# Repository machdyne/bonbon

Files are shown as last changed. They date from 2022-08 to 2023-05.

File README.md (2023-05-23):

# Bonbon Computer

Bonbon is a compact FPGA computer designed by Lone Dynamics Corporation.

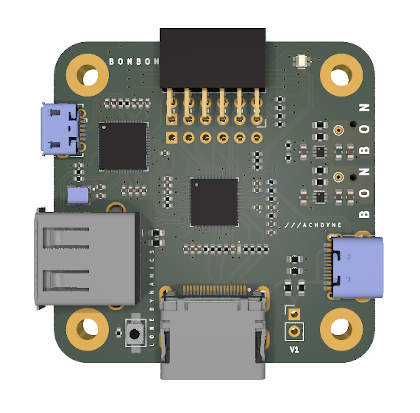
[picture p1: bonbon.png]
Bonbon Computer


This repo contains schematics, PCB layouts, pinouts, example firmware, gateware and documentation.

Find more information on the [Bonbon product page](https://machdyne.com/product/bonbon-computer/).

## Blinky 

Building the blinky example requires [Yosys](https://github.com/YosysHQ/yosys), [nextpnr-ice40](https://github.com/YosysHQ/nextpnr) and [IceStorm](https://github.com/YosysHQ/icestorm).

Assuming they are installed, you can simply type `make` to build the gateware, which will be written to output/blinky.bin. You can then connect the Micro-USB port to your computer and use the latest version of [ldprog](https://github.com/machdyne/ldprog) to write the gateware to the device.

## Programming

The RP2040 firmware, FPGA SRAM and flash MMOD can be programmed over the Micro-USB port.

Configure the FPGA SRAM:

```
$ ldprog -b -s blinky.bin
```

Program the flash MMOD:

```
$ ldprog -b -f blinky.bin
```

Note: It should also be possible to program the MMOD over the USB-C port with a USB bootloader but this is not yet officially supported.

## Firmware

Bonbon ships with RP2040 [firmware](firmware) based on the [Müsli](https://github.com/machdyne/musli) firmware which allows it to communicate with [ldprog](https://github.com/machdyne/ldprog).

The firmware is responsible for initializing the system, [configuring and outputting the system clock](https://raspberrypi.github.io/pico-sdk-doxygen/group__hardware__clocks.html#details), and either configuring the FPGA or telling the FPGA to configure itself from the MMOD.

The system clock (CLK\_RP) is 48MHz by default.

The firmware can be updated by holding down the BOOTSEL button, connecting the Micro-USB port to your computer, and then dragging and dropping a new UF2 file to the device filesystem.

## DDMI

See this [SmolDVI fork](https://github.com/machdyne/SmolDVI) for an example of outputting video on the DDMI port.

## Pinouts

 * [MMOD](https://github.com/machdyne/mmod)
 * [DDMI](https://github.com/machdyne/ddmi)

## License

The contents of this repo are released under the [Lone Dynamics Open License](LICENSE.md) with the following exceptions:

- The KiCad design files contain parts of the [kicad-pmod](https://github.com/mithro/kicad-pmod) library which is released under the [Apache License, Version 2.0](https://www.apache.org/licenses/LICENSE-2.0.html).

- The KiCad design files may contain symbols and footprints released under other licenses; please contact us if we've failed to give proper attribution.

Note: You can use these designs for commercial purposes but we ask that instead of producing exact clones, that you either replace our trademarks and logos with your own or add your own next to ours.

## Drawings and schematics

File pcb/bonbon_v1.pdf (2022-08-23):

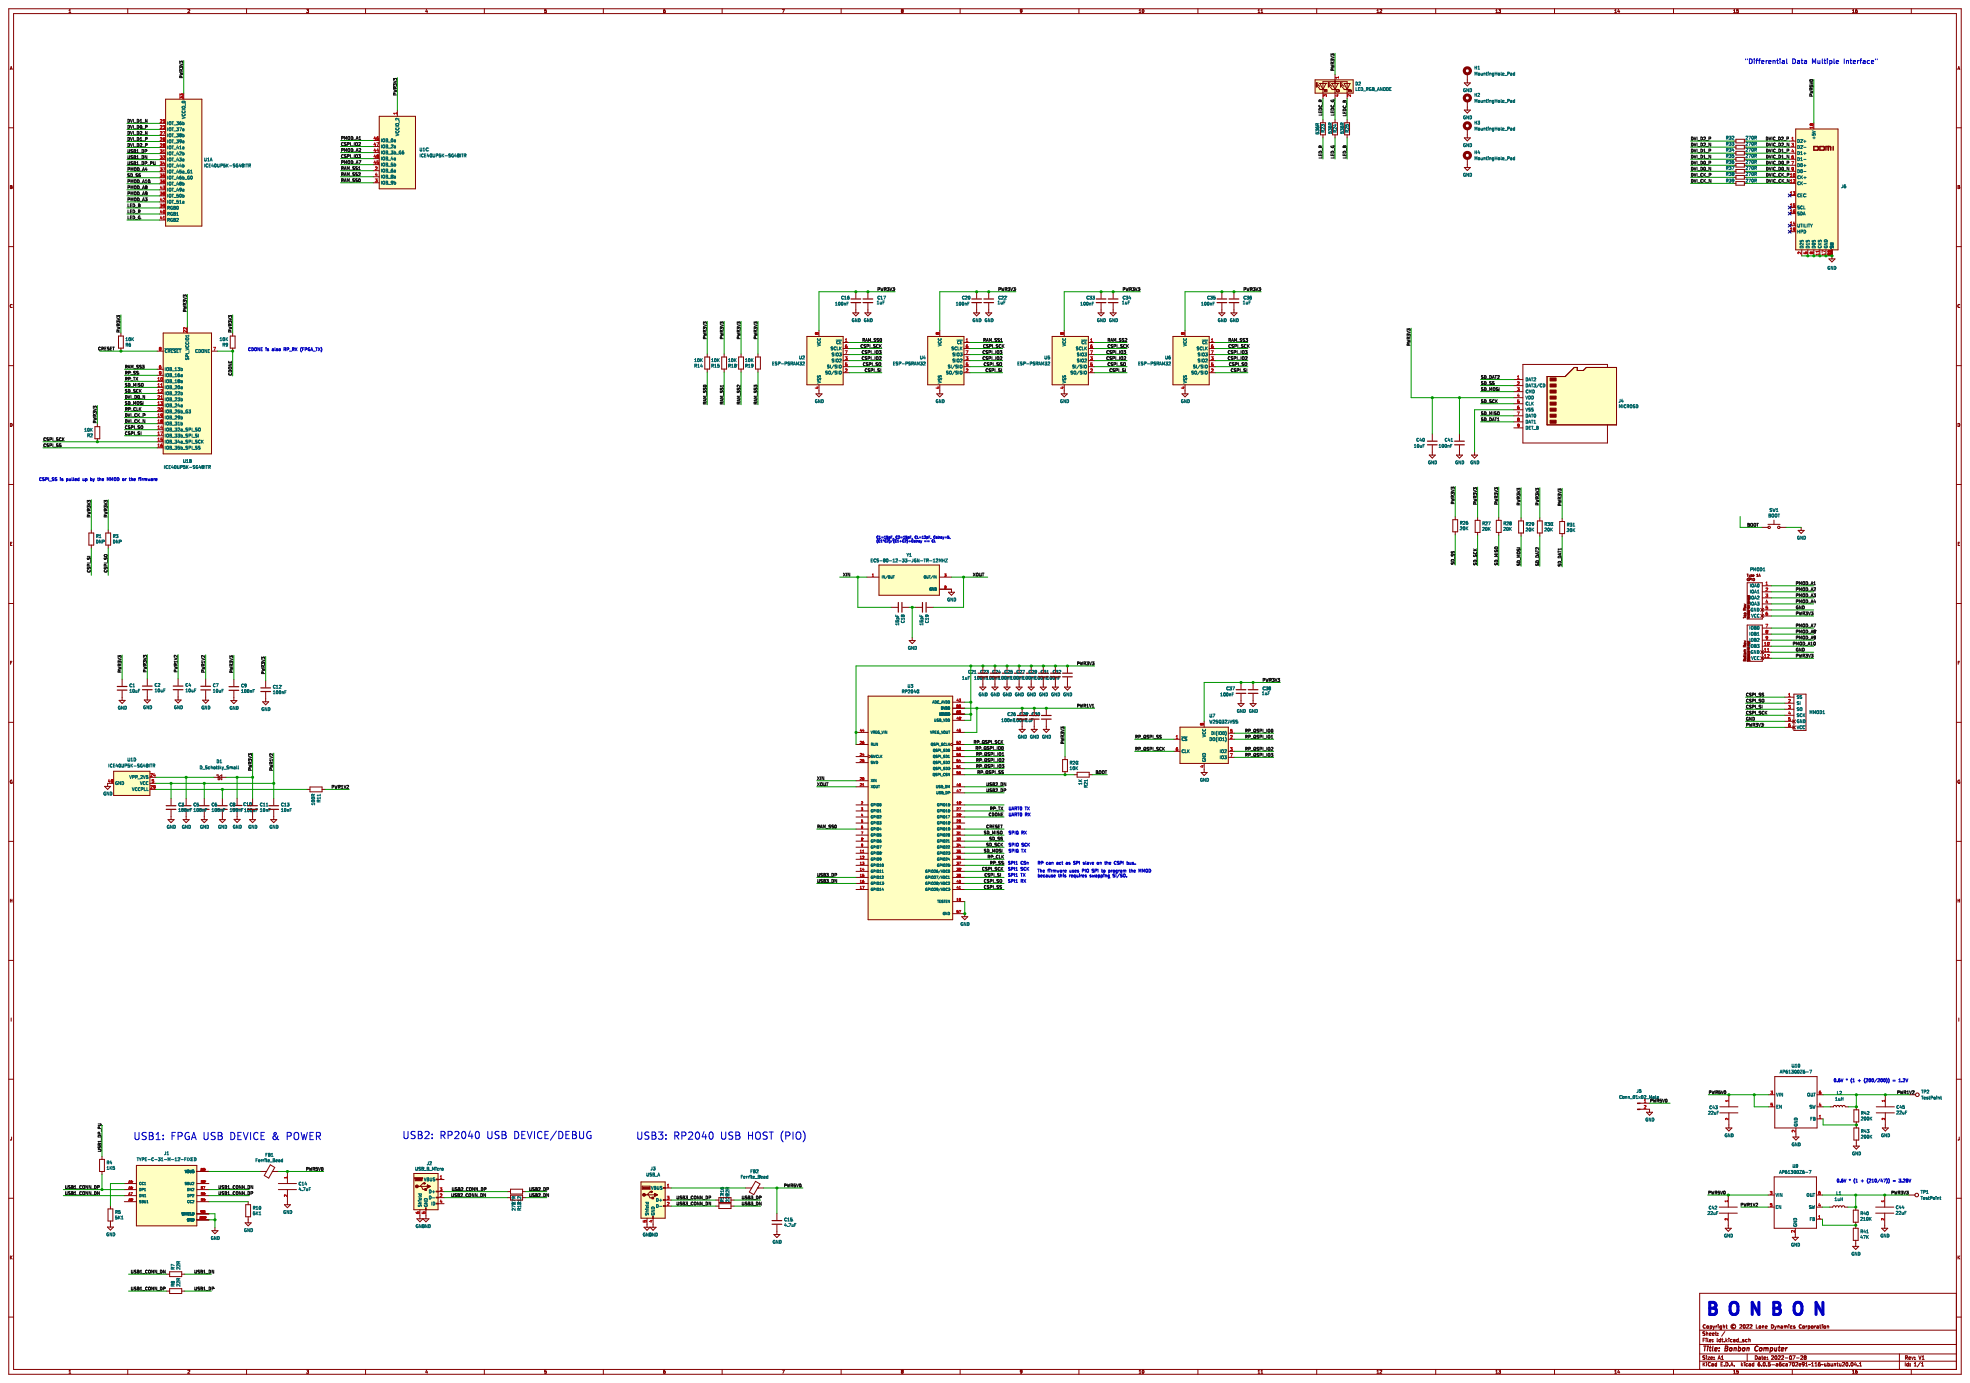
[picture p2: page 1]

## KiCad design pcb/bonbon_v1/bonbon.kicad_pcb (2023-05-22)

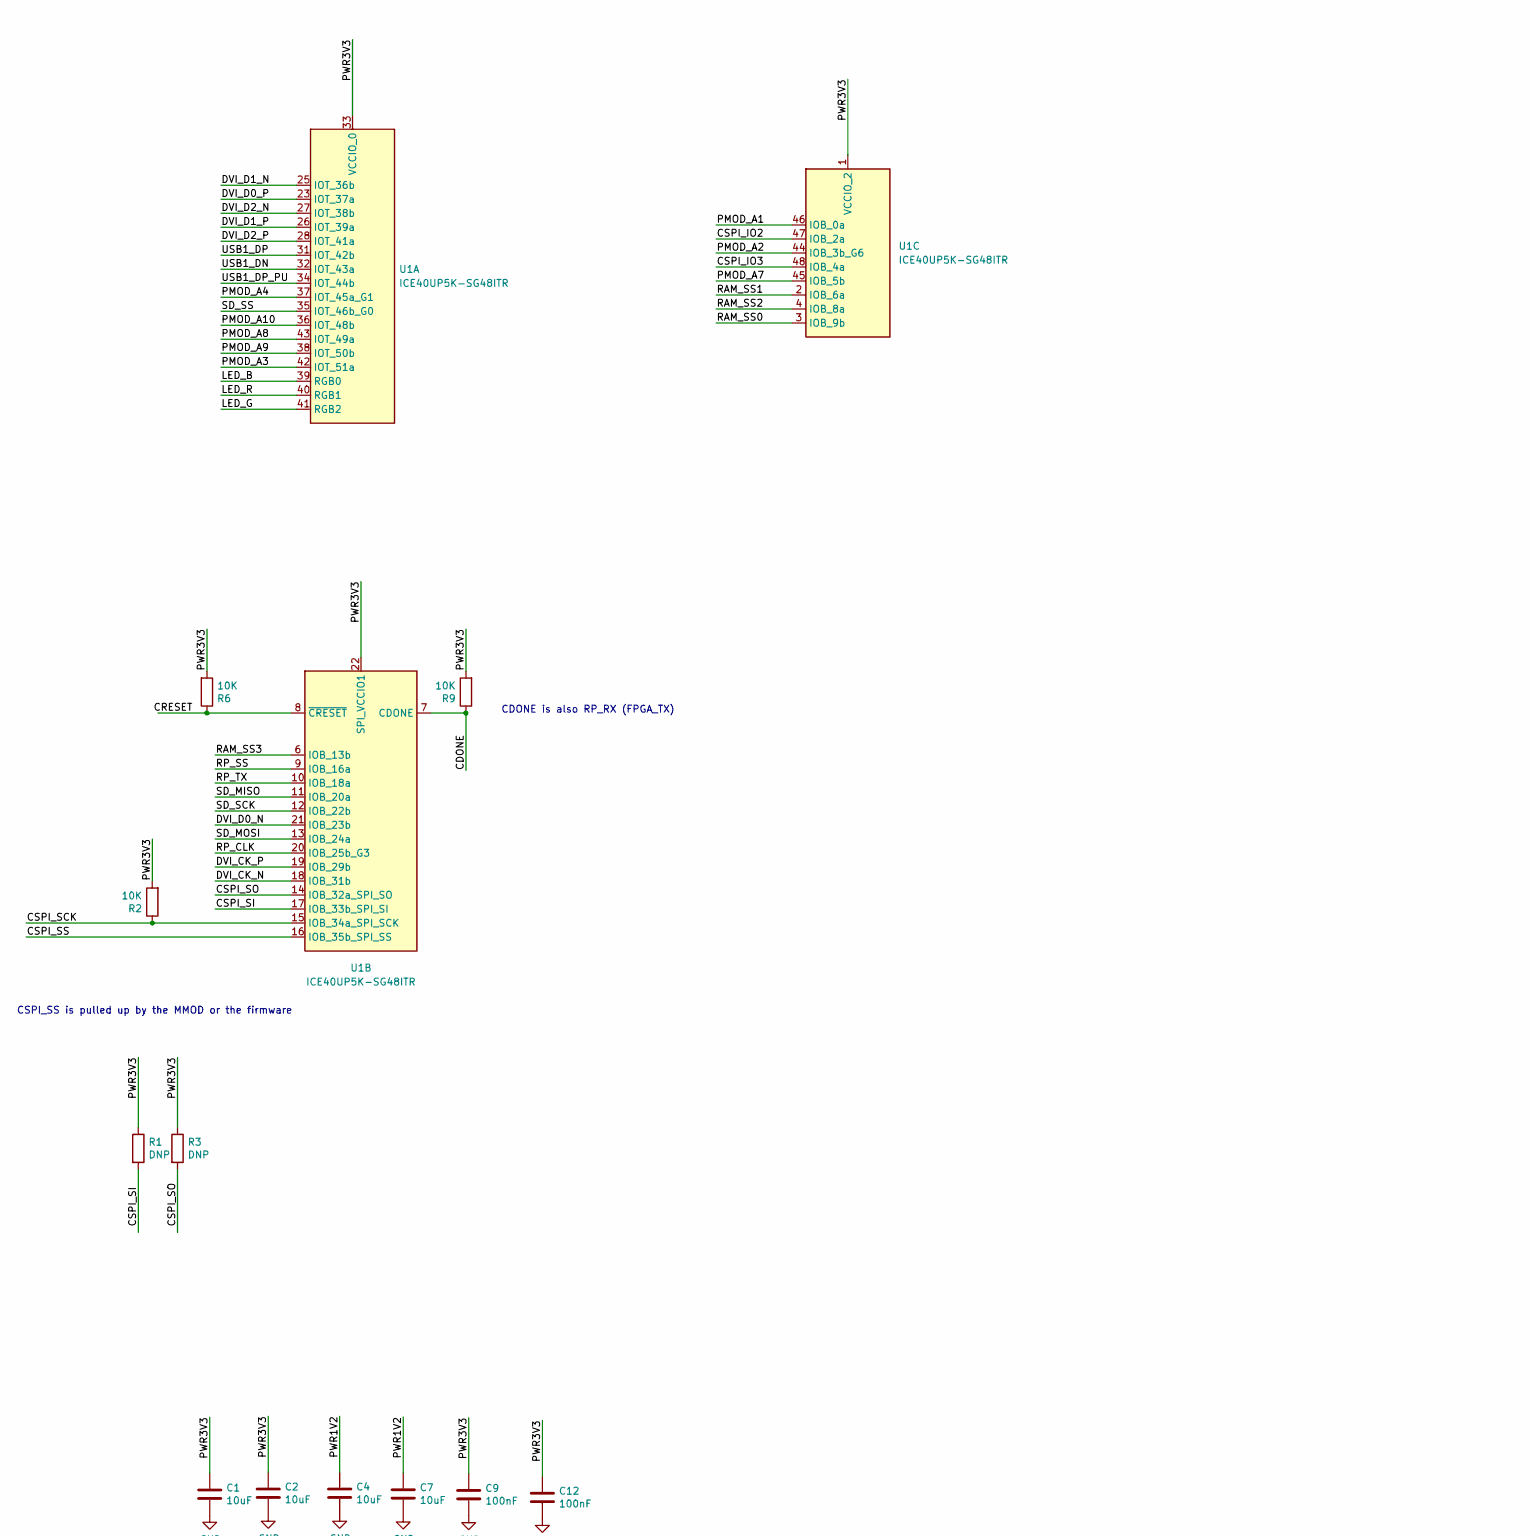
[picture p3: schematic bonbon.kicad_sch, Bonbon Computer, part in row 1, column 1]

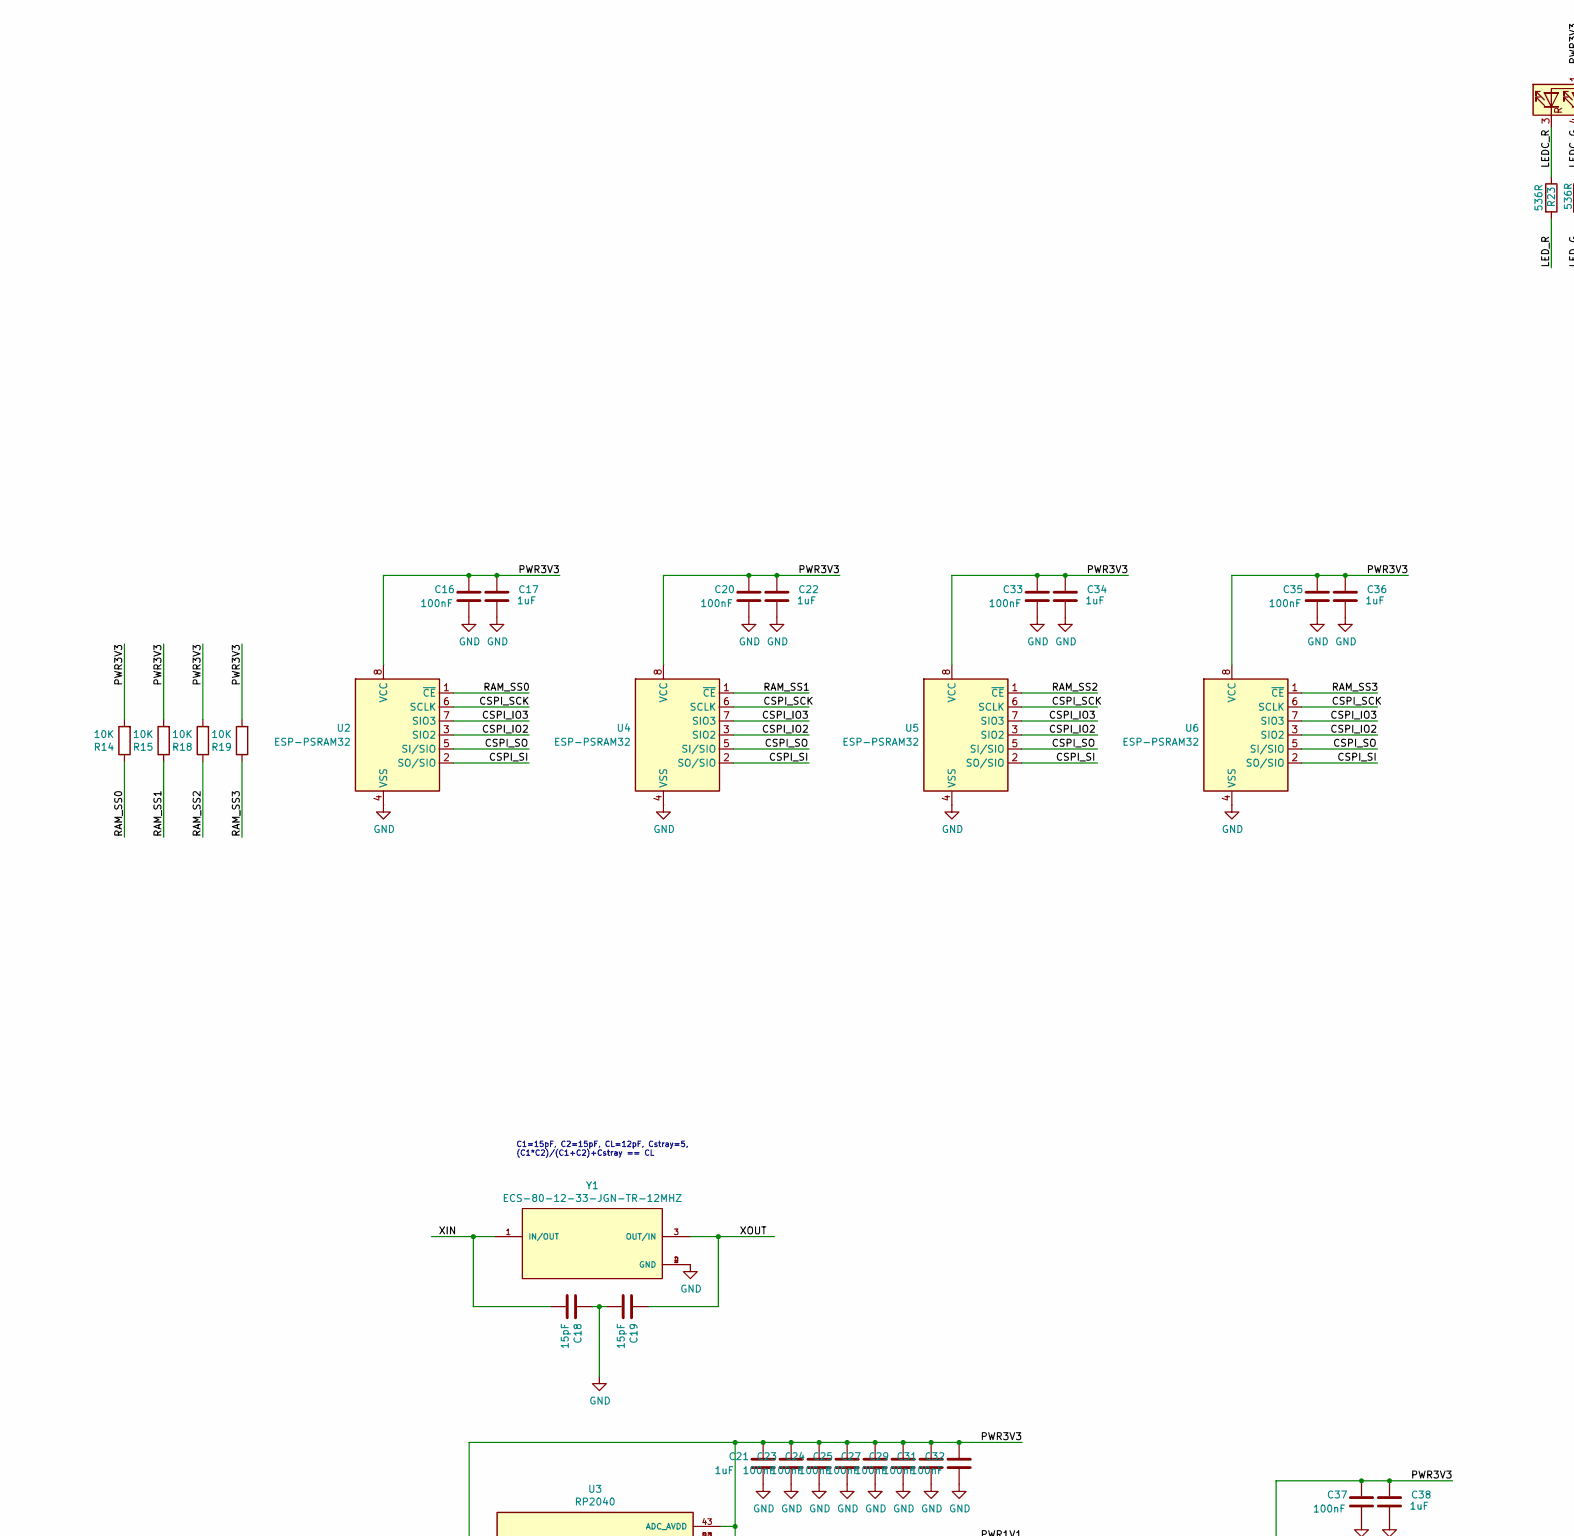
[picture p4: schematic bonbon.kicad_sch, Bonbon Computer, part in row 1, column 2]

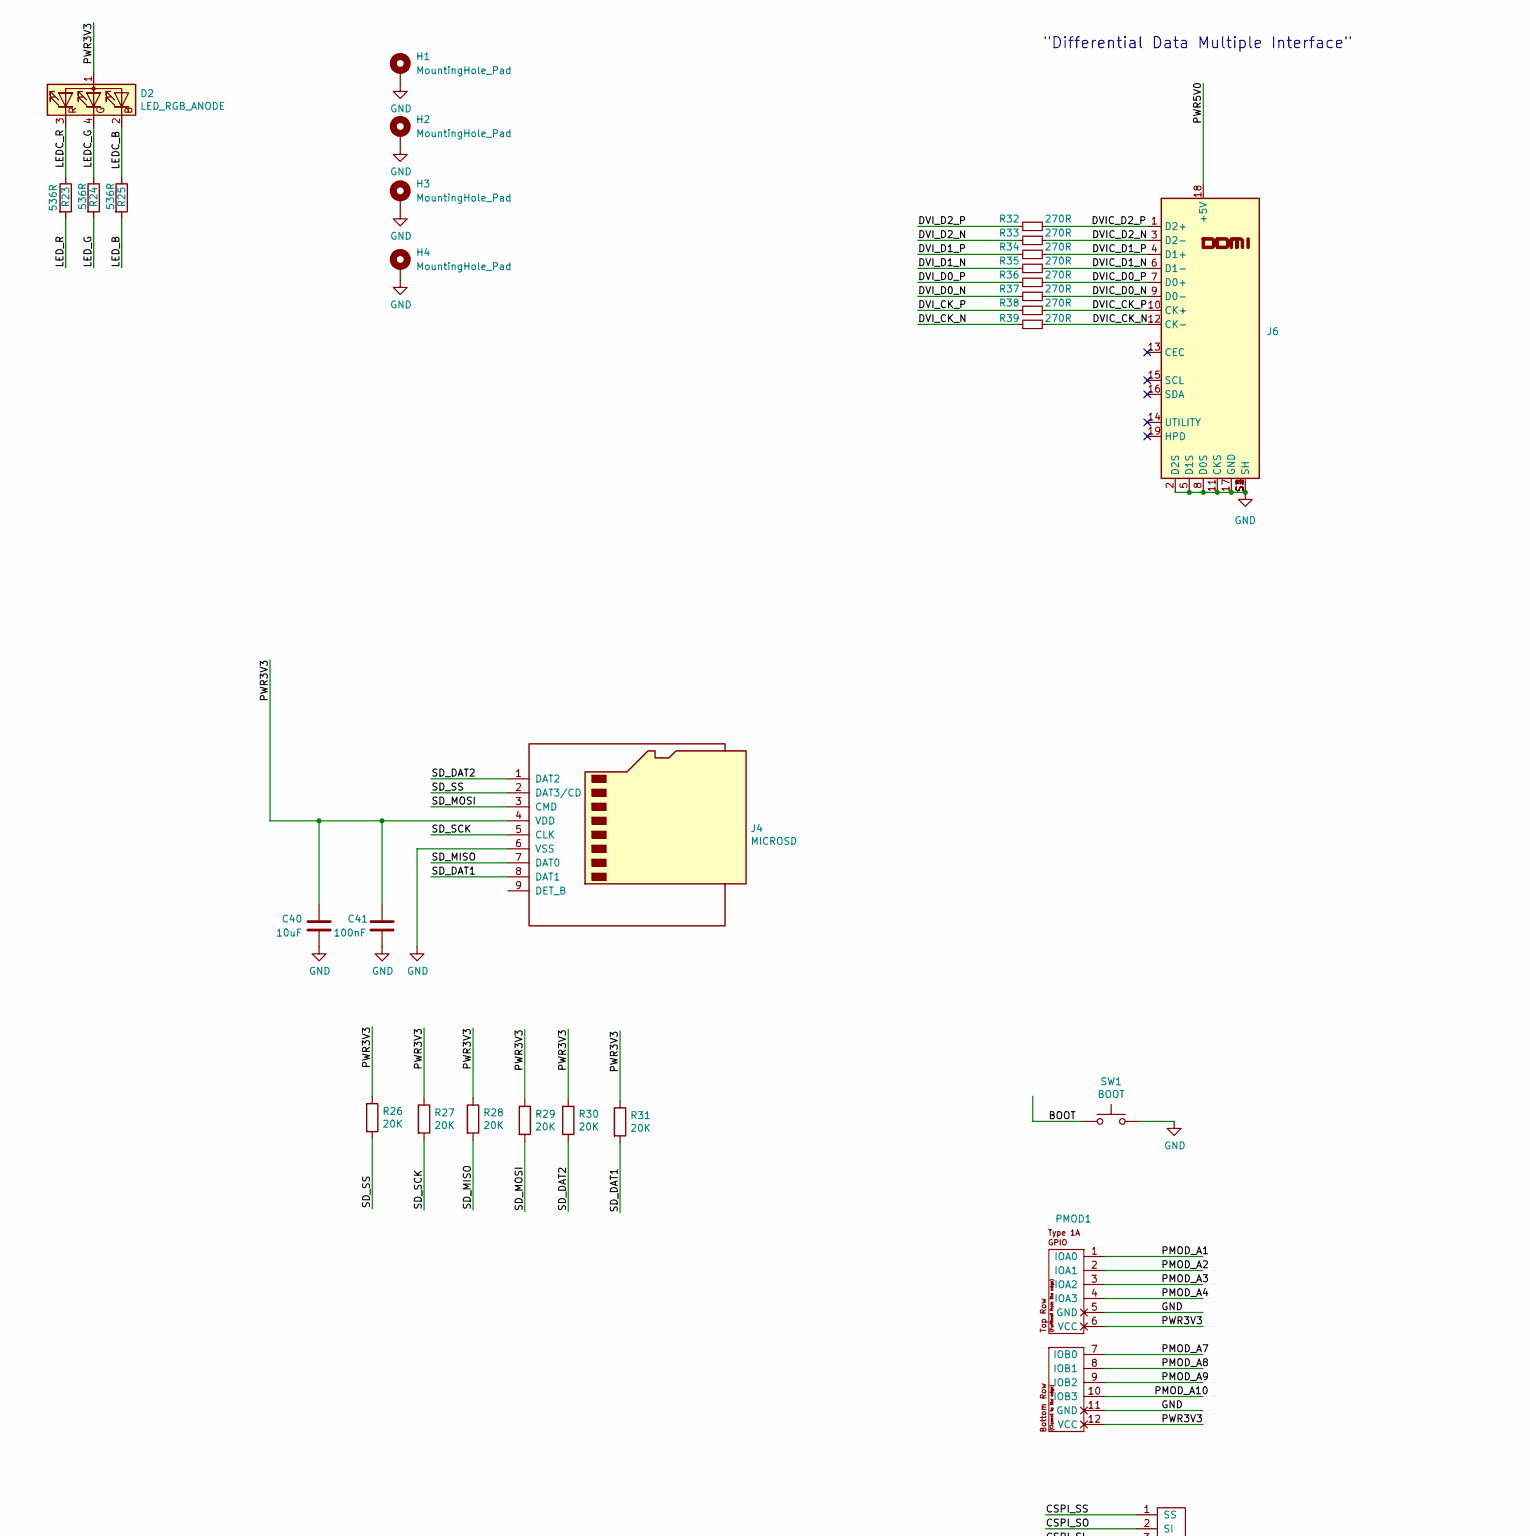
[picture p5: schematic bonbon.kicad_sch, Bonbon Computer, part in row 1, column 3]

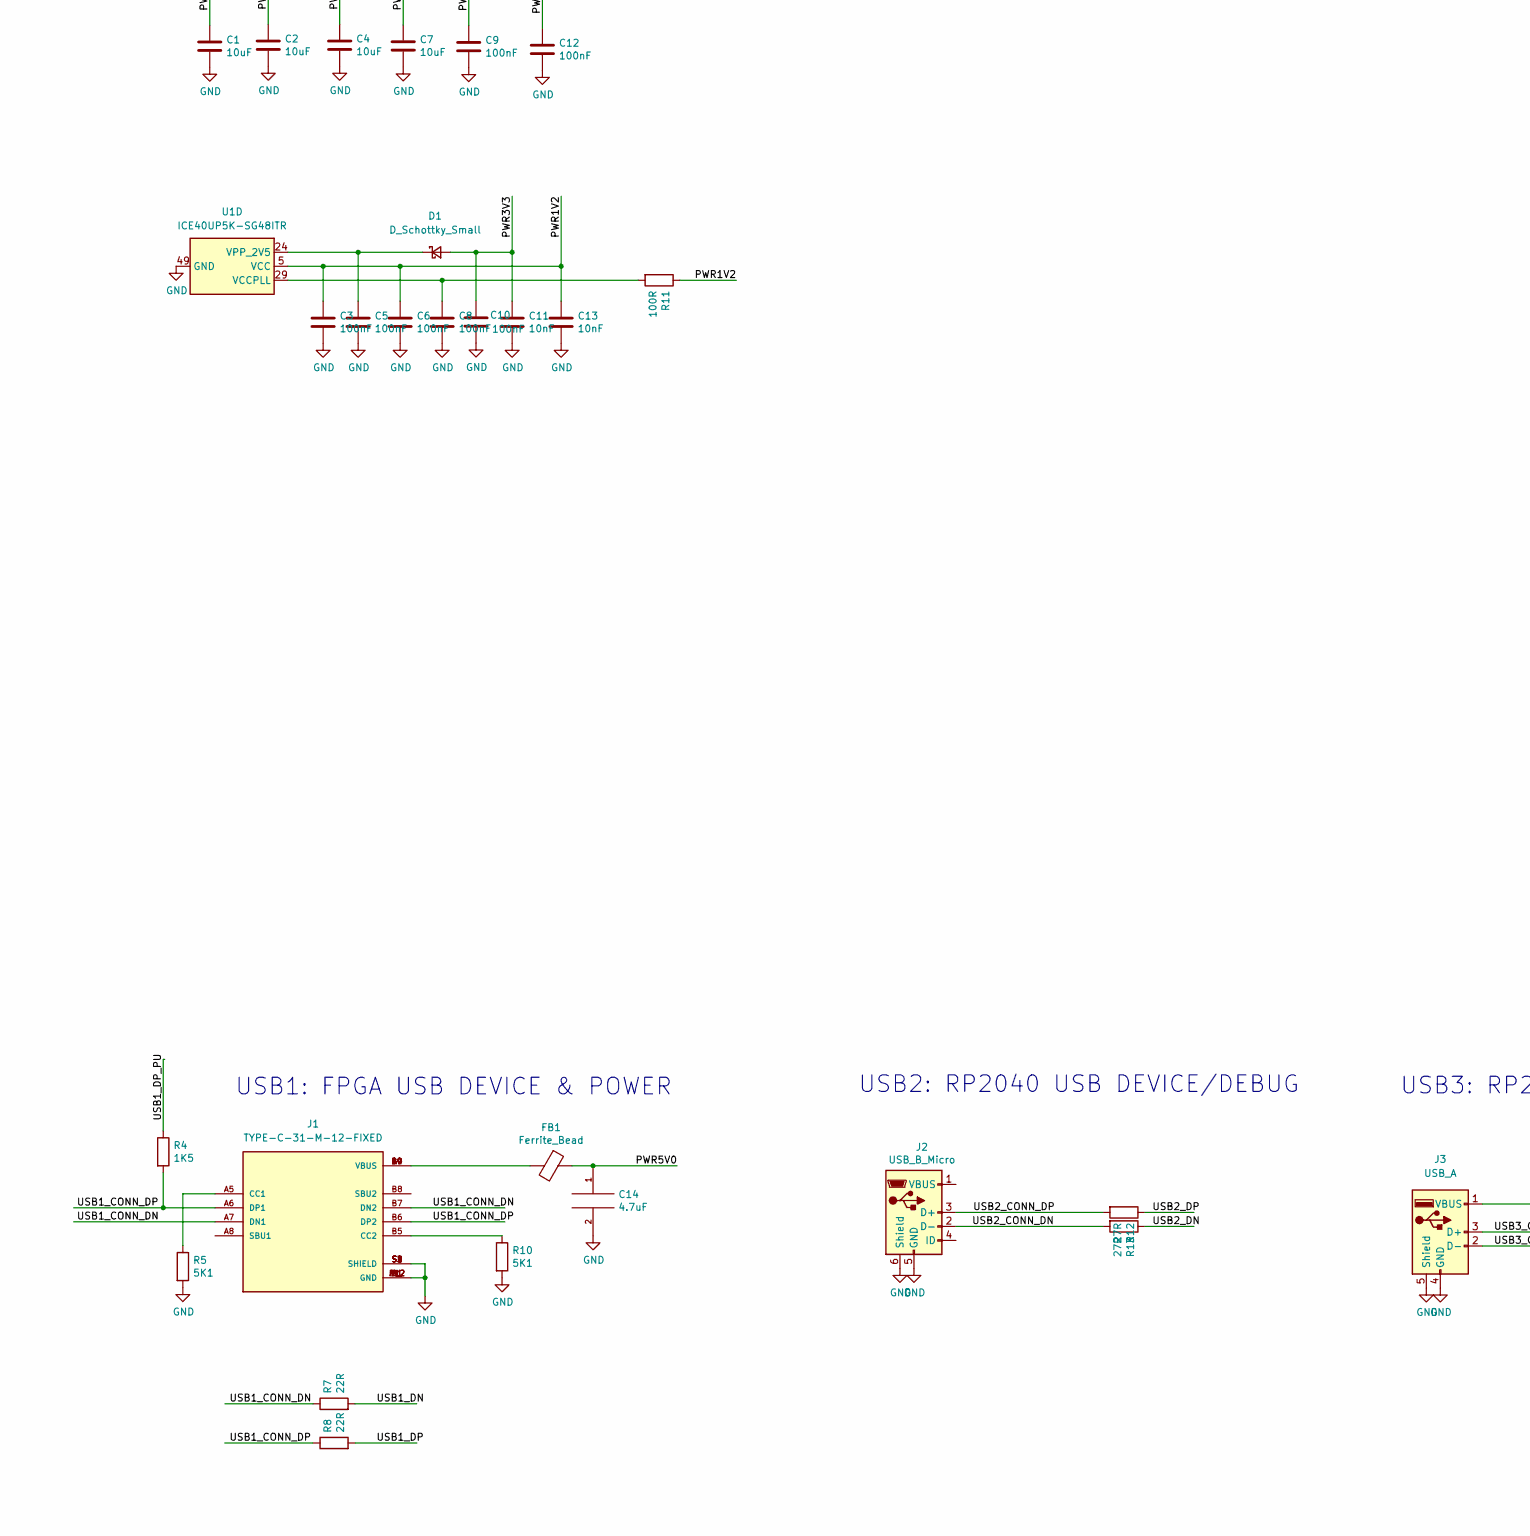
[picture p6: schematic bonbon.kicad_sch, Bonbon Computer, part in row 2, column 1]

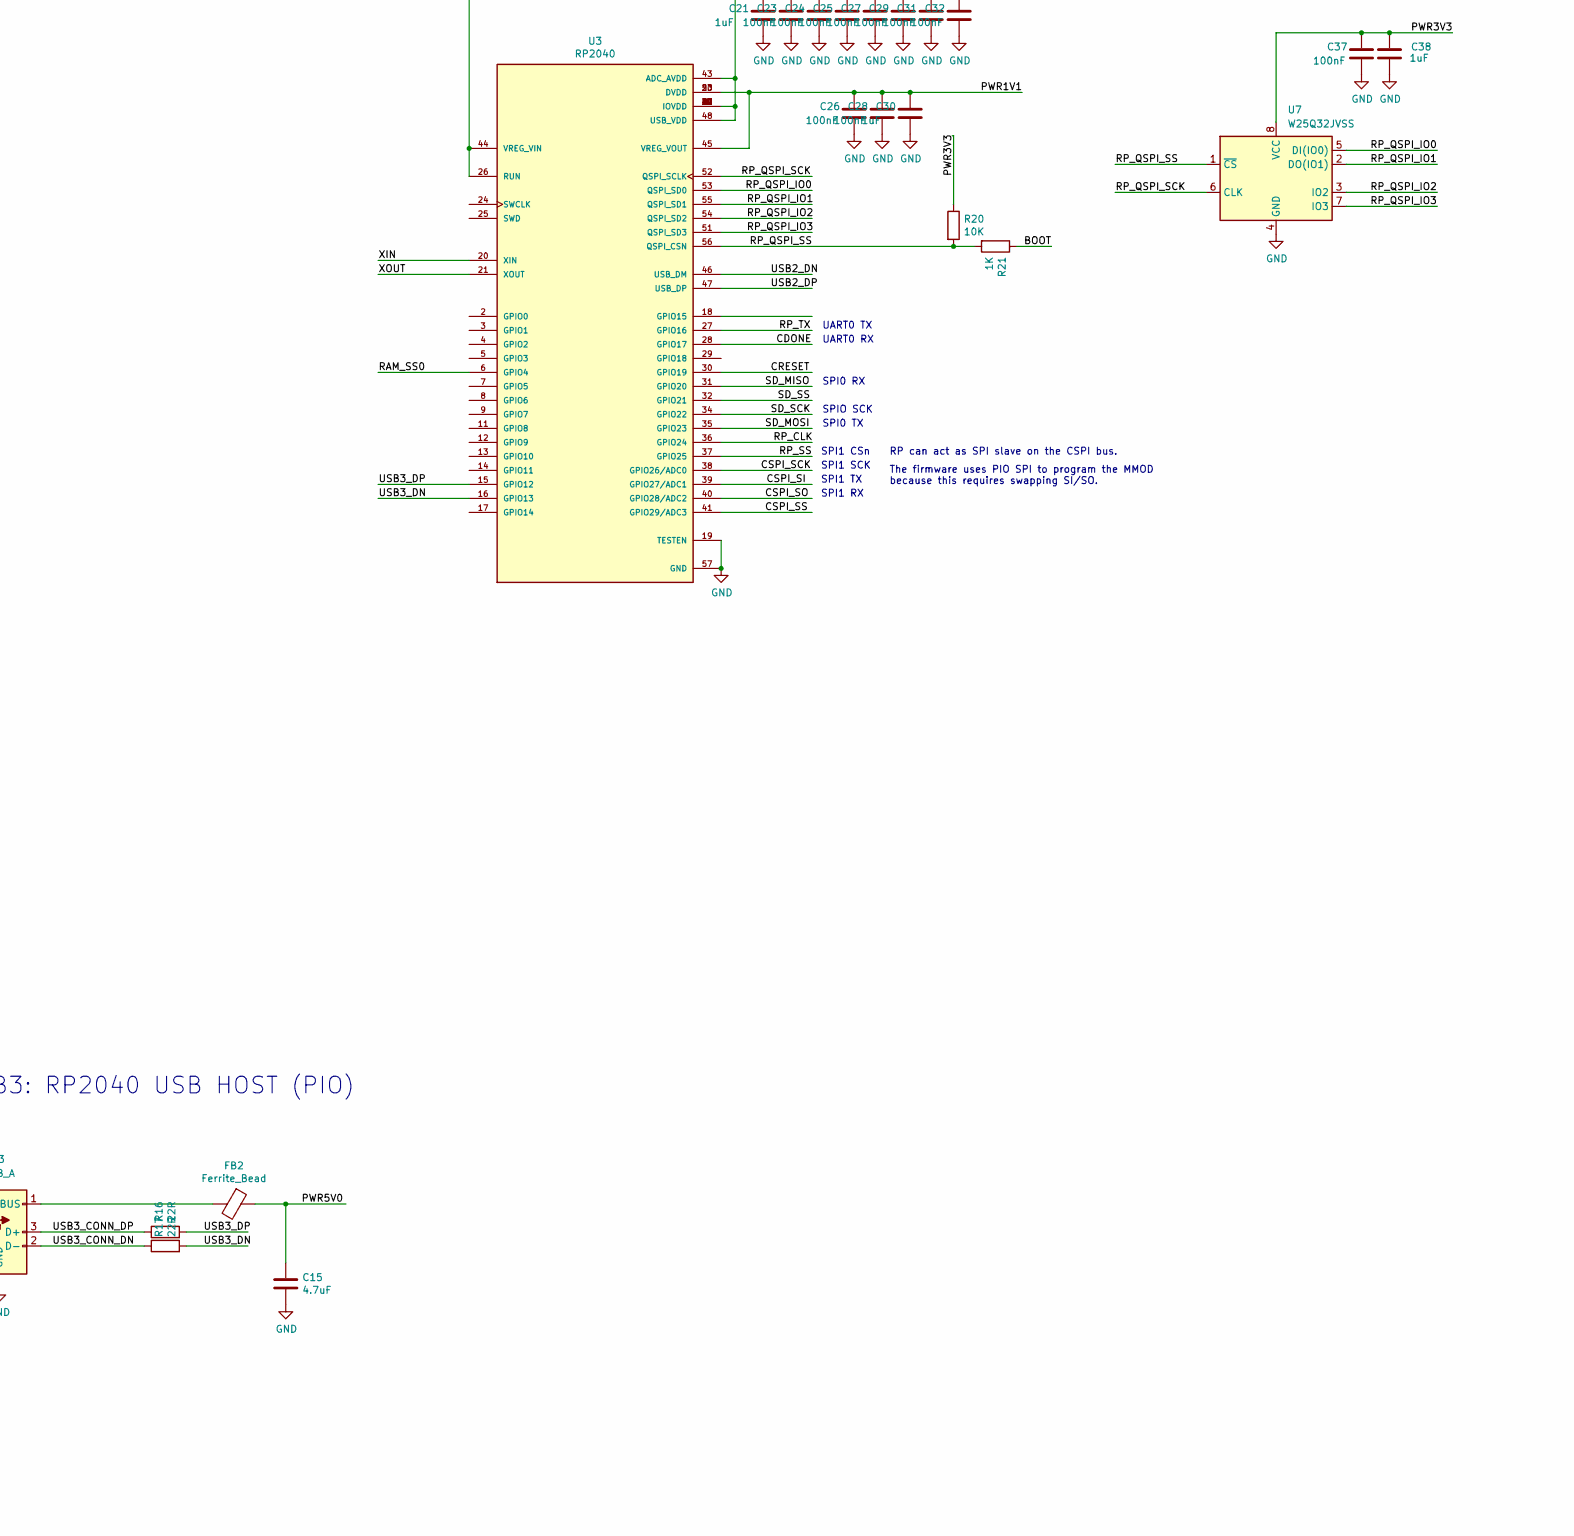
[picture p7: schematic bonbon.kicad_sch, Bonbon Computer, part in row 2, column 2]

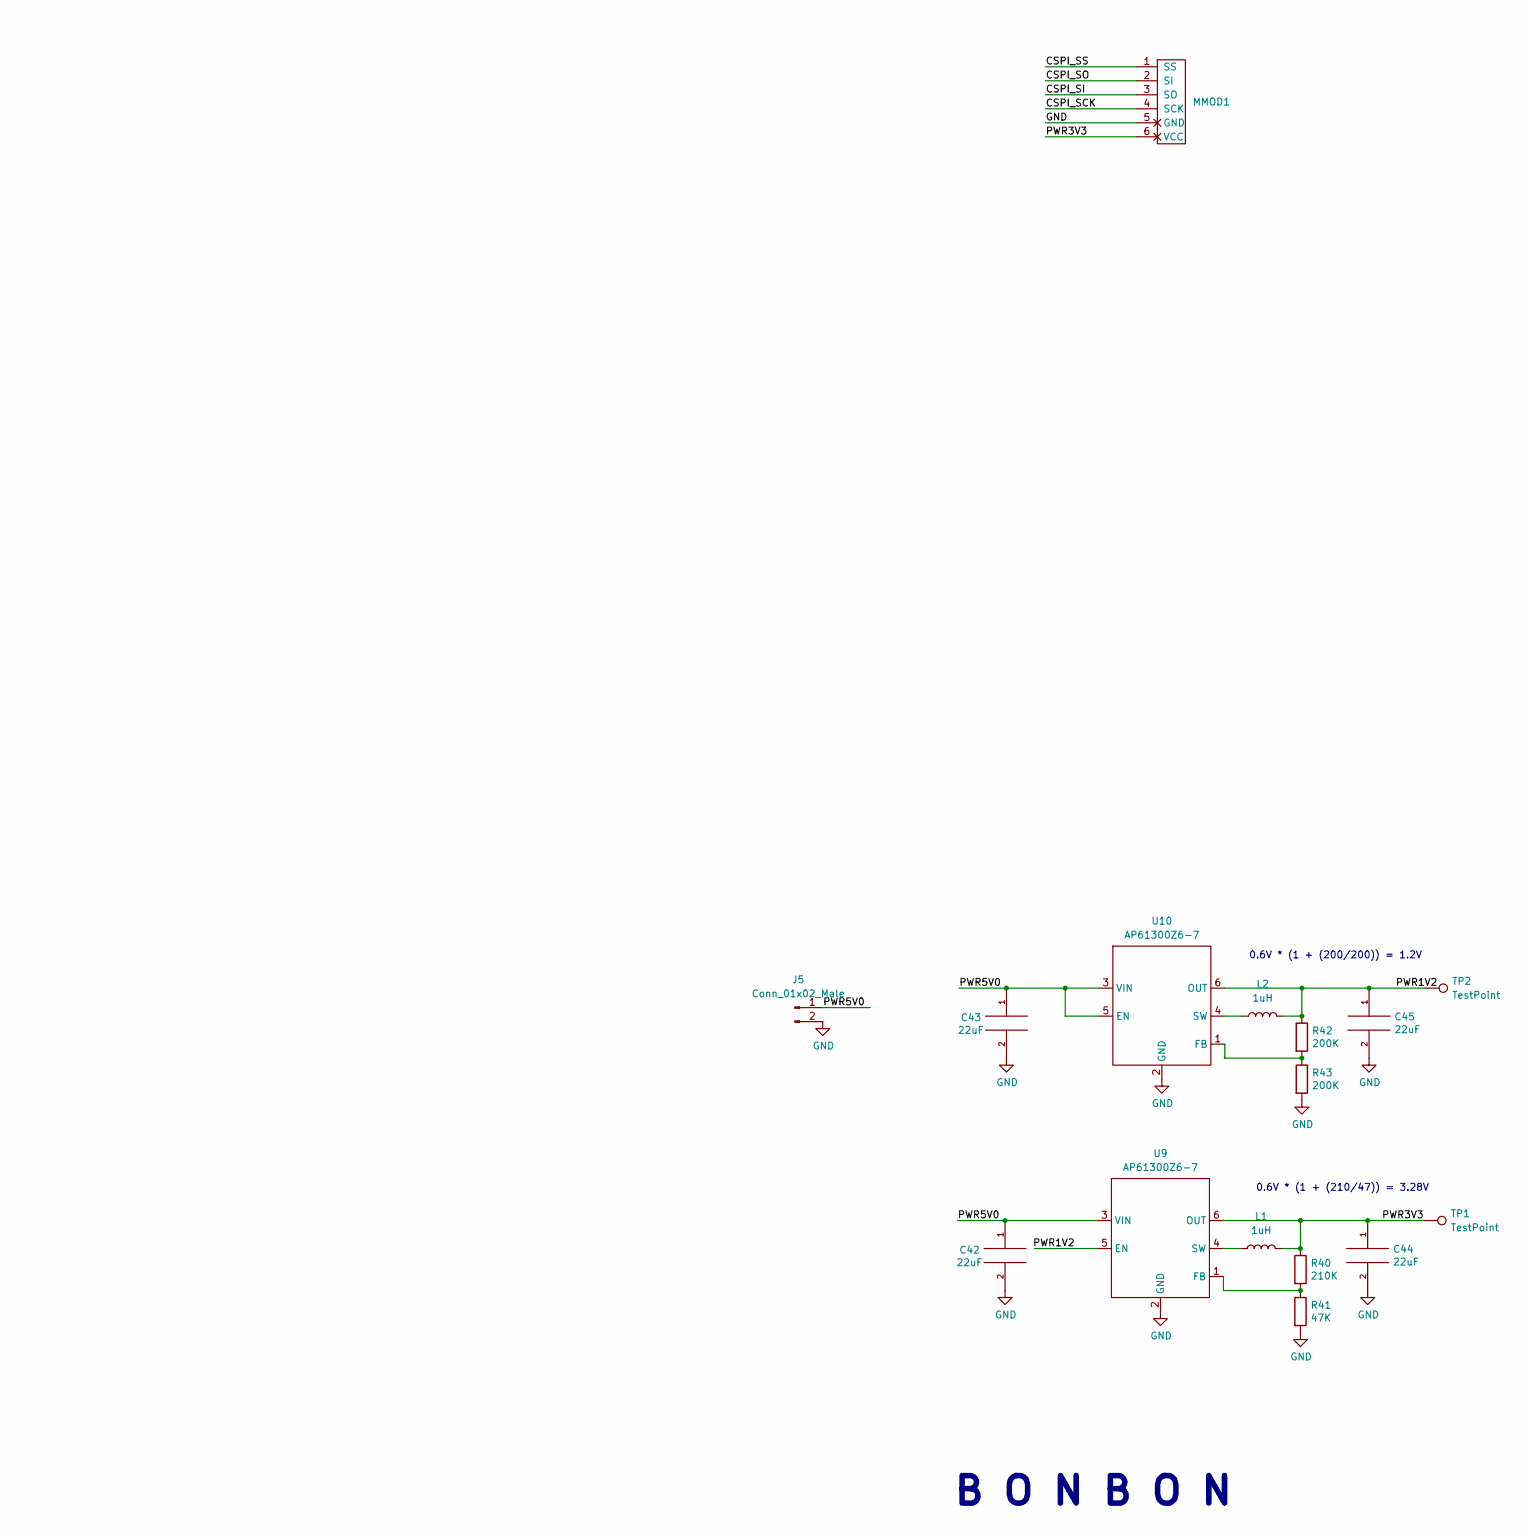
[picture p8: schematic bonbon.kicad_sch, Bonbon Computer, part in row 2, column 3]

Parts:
C1, C2, C4, C7: 10uF; C_0402_1005Metric
C3, C5, C6, C8, C9, C10, C12, C16, C20, C23, C24, C25, C26, C27, C28, C29, C31, C32, C33, C35, C37: 100nF; C_0402_1005Metric
C11, C13: 10nF; C_0402_1005Metric
C14, C15: 4.7uF; R_0603_1608Metric
C17, C21, C22, C30, C34, C36, C38: 1uF; C_0402_1005Metric
C18, C19: 15pF; C_0402_1005Metric
C40: 10uF; R_0402_1005Metric
C41: 100nF; R_0402_1005Metric
C42, C43, C44, C45: 22uF; C_0603_1608Metric
D1: D_Schottky_Small; D_0402_1005Metric
D2: LED_RGB_ANODE; LED_RGB_0606_CHANZON
FB1, FB2: Ferrite_Bead; R_0603_1608Metric
H1, H2, H3, H4: MountingHole_Pad; MountingHole_3.2mm_M3_Pad
J1: TYPE-C-31-M-12-FIXED; USB_C_Receptacle_HRO_TYPE-C-31-M-12-BIG-PADS; PARTREV A
J2: USB_B_Micro; USB_Micro-B_Molex-105017-0001
J3: USB_A; USB_A_Stewart_SS-52100-001_Horizontal
J4: MICROSD; SDCARD
J5: Conn_01x02_Male; PinHeader_1x02_P2.54mm_Vertical
J6: HDMI_TE_1827059-3-FIXED
L1, L2: 1uH; L_0603_1608Metric
MMOD1: MMOD_Host_Socket
PMOD1: PMOD-Device-x2-Type-1A-GPIO; PMOD_2x06_HOST
R1, R3: DNP; R_0402_1005Metric
R2, R6, R9, R14, R15, R18, R19, R20: 10K; R_0402_1005Metric
R4: 1K5; R_0402_1005Metric
R5, R10: 5K1; R_0603_1608Metric
R7, R8, R16, R17: 22R; R_0402_1005Metric
R11: 100R; R_0402_1005Metric
R12, R13: 27R; R_0402_1005Metric
R21: 1K; R_0402_1005Metric
R23, R24, R25: 536R; R_0402_1005Metric
R26, R27, R28, R29, R30, R31: 20K; R_0402_1005Metric
R32, R33, R34, R35, R36, R37, R38, R39: 270R; R_0402_1005Metric
R40: 210K; R_0603_1608Metric
R41: 47K; R_0603_1608Metric
R42, R43: 200K; R_0603_1608Metric
SW1: BOOT; Button_2P_3x4mm
TP1, TP2: TestPoint; TestPoint_THTPad_D1.0mm_Drill0.5mm
U1: ICE40UP5K-SG48ITR; QFN-48-1EP_7x7mm_P0.5mm_EP5.6x5.6mm
U2, U4, U5, U6: ESP-PSRAM32; SOIC-8_3.9x4.9mm_P1.27mm
U3: RP2040; RP2040-QFN-56-OFFICIAL; PARTREV 1.6.1
U7: W25Q32JVSS; SOIC-8_3.9x4.9mm_P1.27mm
U9, U10: AP61300Z6-7; SOT-563
Y1: ECS-80-12-33-JGN-TR-12MHZ; XTAL_ECS-240-8-33-AGN-TR

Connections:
/BOOT: R21.1, SW1.1
/CDONE: R9.1, U1.7 (CDONE), U3.28 (GPIO17)
/CRESET: R6.1, U1.8 (~CRESET), U3.30 (GPIO19)
/CSPI_IO2: U1.47 (IOB_2a), U2.3 (SIO2), U4.3 (SIO2), U5.3 (SIO2), U6.3 (SIO2)
/CSPI_IO3: U1.48 (IOB_4a), U2.7 (SIO3), U4.7 (SIO3), U5.7 (SIO3), U6.7 (SIO3)
/CSPI_SCK: MMOD1.4 (SCK), R2.1, U1.15 (IOB_34a_SPI_SCK), U2.6 (SCLK), U3.38 (GPIO26/ADC0), U4.6 (SCLK), U5.6 (SCLK), U6.6 (SCLK)
/CSPI_SI: MMOD1.3 (SO), R1.2, U1.17 (IOB_33b_SPI_SI), U2.2 (SO/SIO), U3.39 (GPIO27/ADC1), U4.2 (SO/SIO), U5.2 (SO/SIO), U6.2 (SO/SIO)
/CSPI_SO: MMOD1.2 (SI), R3.2, U1.14 (IOB_32a_SPI_SO), U2.5 (SI/SIO), U3.40 (GPIO28/ADC2), U4.5 (SI/SIO), U5.5 (SI/SIO), U6.5 (SI/SIO)
/CSPI_SS: MMOD1.1 (SS), U1.16 (IOB_35b_SPI_SS), U3.41 (GPIO29/ADC3)
/DVIC_CK_N: J6.12 (CK-), R39.2
/DVIC_CK_P: J6.10 (CK+), R38.2
/DVIC_D0_N: J6.9 (D0-), R37.2
/DVIC_D0_P: J6.7 (D0+), R36.2
/DVIC_D1_N: J6.6 (D1-), R35.2
/DVIC_D1_P: J6.4 (D1+), R34.2
/DVIC_D2_N: J6.3 (D2-), R33.2
/DVIC_D2_P: J6.1 (D2+), R32.2
/DVI_CK_N: R39.1, U1.18 (IOB_31b)
/DVI_CK_P: R38.1, U1.19 (IOB_29b)
/DVI_D0_N: R37.1, U1.21 (IOB_23b)
/DVI_D0_P: R36.1, U1.23 (IOT_37a)
/DVI_D1_N: R35.1, U1.25 (IOT_36b)
/DVI_D1_P: R34.1, U1.26 (IOT_39a)
/DVI_D2_N: R33.1, U1.27 (IOT_38b)
/DVI_D2_P: R32.1, U1.28 (IOT_41a)
/LEDC_B: D2.2 (BK), R25.1
/LEDC_G: D2.4 (GK), R24.1
/LEDC_R: D2.3 (RK), R23.1
/LED_B: R25.2, U1.39 (RGB0)
/LED_G: R24.2, U1.41 (RGB2)
/LED_R: R23.2, U1.40 (RGB1)
/PMOD_A1: PMOD1.1 (IOA0), U1.46 (IOB_0a)
/PMOD_A2: PMOD1.2 (IOA1), U1.44 (IOB_3b_G6)
/PMOD_A3: PMOD1.3 (IOA2), U1.42 (IOT_51a)
/PMOD_A4: PMOD1.4 (IOA3), U1.37 (IOT_45a_G1)
/PMOD_A7: PMOD1.7 (IOB0), U1.45 (IOB_5b)
/PMOD_A8: PMOD1.8 (IOB1), U1.43 (IOT_49a)
/PMOD_A9: PMOD1.9 (IOB2), U1.38 (IOT_50b)
/PMOD_A10: PMOD1.10 (IOB3), U1.36 (IOT_48b)
/PWR1V1: C26.1, C28.1, C30.1, U3.23 (DVDD), U3.45 (VREG_VOUT), U3.50 (DVDD)
/PWR1V2: C3.1, C4.1, C6.1, C7.1, C13.1, C45.1, L2.2, R11.1, R42.1, TP2.1, U1.5 (VCC), U1.30 (VCC), U9.5 (EN), U10.6 (OUT)
/PWR3V3: C1.1, C2.1, C9.1, C10.1, C11.1, C12.1, C16.1, C17.1, C20.1, C21.1, C22.1, C23.1, C24.1, C25.1, C27.1, C29.1, C31.1, C32.1, C33.1, C34.1, C35.1, C36.1, C37.1, C38.1, C40.1, C41.1, C44.1, D1.2 (A), D2.1 (A), J4.4 (VDD), L1.2, MMOD1.6 (VCC), PMOD1.6 (VCC), PMOD1.12 (VCC), R1.1, R2.2, R3.1, R6.2, R9.2, R14.2, R15.2, R18.2, R19.2, R20.1, R26.1, R27.1, R28.1, R29.1, R30.1, R31.1, R40.1, TP1.1, U1.1 (VCCIO_2), U1.22 (SPI_VCCIO1), U1.33 (VCCIO_0), U2.8 (VCC), U3.1 (IOVDD), U3.10 (IOVDD), U3.22 (IOVDD), U3.26 (RUN), U3.33 (IOVDD), U3.42 (IOVDD), U3.43 (ADC_AVDD), U3.44 (VREG_VIN), U3.48 (USB_VDD), U3.49 (IOVDD), U4.8 (VCC), U5.8 (VCC), U6.8 (VCC), U7.8 (VCC), U9.6 (OUT)
/PWR5V0: C14.1, C15.1, C42.1, C43.1, FB1.1, FB2.1, J5.1, J6.18 (+5V), U9.3 (VIN), U10.3 (VIN), U10.5 (EN)
/RAM_SS0: R14.1, U1.3 (IOB_9b), U2.1 (~CE), U3.6 (GPIO4)
/RAM_SS1: R15.1, U1.2 (IOB_6a), U4.1 (~CE)
/RAM_SS2: R18.1, U1.4 (IOB_8a), U5.1 (~CE)
/RAM_SS3: R19.1, U1.6 (IOB_13b), U6.1 (~CE)
/RP_CLK: U1.20 (IOB_25b_G3), U3.36 (GPIO24)
/RP_QSPI_IO0: U3.53 (QSPI_SD0), U7.5 (DI(IO0))
/RP_QSPI_IO1: U3.55 (QSPI_SD1), U7.2 (DO(IO1))
/RP_QSPI_IO2: U3.54 (QSPI_SD2), U7.3 (IO2)
/RP_QSPI_IO3: U3.51 (QSPI_SD3), U7.7 (IO3)
/RP_QSPI_SCK: U3.52 (QSPI_SCLK), U7.6 (CLK)
/RP_QSPI_SS: R20.2, R21.2, U3.56 (QSPI_CSN), U7.1 (~CS)
/RP_SS: U1.9 (IOB_16a), U3.37 (GPIO25)
/RP_TX: U1.10 (IOB_18a), U3.27 (GPIO16)
/SD_DAT1: J4.8 (DAT1), R31.2
/SD_DAT2: J4.1 (DAT2), R30.2
/SD_MISO: J4.7 (DAT0), R28.2, U1.11 (IOB_20a), U3.31 (GPIO20)
/SD_MOSI: J4.3 (CMD), R29.2, U1.13 (IOB_24a), U3.35 (GPIO23)
/SD_SCK: J4.5 (CLK), R27.2, U1.12 (IOB_22b), U3.34 (GPIO22)
/SD_SS: J4.2 (DAT3/CD), R26.2, U1.35 (IOT_46b_G0), U3.32 (GPIO21)
/USB1_CONN_DN: J1.A7 (DN1), J1.B7 (DN2), R7.1
/USB1_CONN_DP: J1.A6 (DP1), J1.B6 (DP2), R4.2, R8.1
/USB1_DN: R7.2, U1.32 (IOT_43a)
/USB1_DP: R8.2, U1.31 (IOT_42b)
/USB1_DP_PU: R4.1, U1.34 (IOT_44b)
/USB2_CONN_DN: J2.2 (D-), R13.2
/USB2_CONN_DP: J2.3 (D+), R12.2
/USB2_DN: R13.1, U3.46 (USB_DM)
/USB2_DP: R12.1, U3.47 (USB_DP)
/USB3_CONN_DN: J3.2 (D-), R17.1
/USB3_CONN_DP: J3.3 (D+), R16.1
/USB3_DN: R17.2, U3.16 (GPIO13)
/USB3_DP: R16.2, U3.15 (GPIO12)
/XIN: C18.2, U3.20 (XIN), Y1.1 (IN/OUT)
/XOUT: C19.1, U3.21 (XOUT), Y1.3 (OUT/IN)
GND: C1.2, C2.2, C3.2, C4.2, C5.2, C6.2, C7.2, C8.2, C9.2, C10.2, C11.2, C12.2, C13.2, C14.2, C15.2, C16.2, C17.2, C18.1, C19.2, C20.2, C21.2, C22.2, C23.2, C24.2, C25.2, C26.2, C27.2, C28.2, C29.2, C30.2, C31.2, C32.2, C33.2, C34.2, C35.2, C36.2, C37.2, C38.2, C40.2, C41.2, C42.2, C43.2, C44.2, C45.2, H1.1, H2.1, H3.1, H4.1, J1.A1 (GND), J1.A12 (GND), J1.B1 (GND), J1.B12 (GND), J1.S1 (SHIELD), J1.S2 (SHIELD), J1.S3 (SHIELD), J1.S4 (SHIELD), J2.5 (GND), J2.6 (Shield), J3.4 (GND), J3.5 (Shield), J4.6 (VSS), J5.2, J6.2 (D2S), J6.5 (D1S), J6.8 (D0S), J6.11 (CKS), J6.17 (GND), J6.S1 (SH), J6.S2 (SH), J6.S3 (SH), J6.S4 (SH), MMOD1.5 (GND), PMOD1.5 (GND), PMOD1.11 (GND), R5.2, R10.2, R41.2, R43.2, SW1.2, U1.49 (GND), U2.4 (VSS), U3.19 (TESTEN), U3.57 (GND), U4.4 (VSS), U5.4 (VSS), U6.4 (VSS), U7.4 (GND), U9.2 (GND), U10.2 (GND), Y1.2 (GND), Y1.4 (GND)
unnamed: C5.1, D1.1 (K), U1.24 (VPP_2V5)
unnamed: C8.1, R11.2, U1.29 (VCCPLL)
unnamed: FB1.2, J1.A4 (VBUS), J1.A9 (VBUS), J1.B4 (VBUS), J1.B9 (VBUS)
unnamed: FB2.2, J3.1 (VBUS)
unnamed: J1.A5 (CC1), R5.1
unnamed: J1.B5 (CC2), R10.1
unnamed: L1.1, U9.4 (SW)
unnamed: L2.1, U10.4 (SW)
unnamed: R40.2, R41.1, U9.1 (FB)
unnamed: R42.2, R43.1, U10.1 (FB)

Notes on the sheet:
CDONE is also RP_RX (FPGA_TX)
UART0 RX
SPI1 TX
USB3: RP2040 USB HOST (PIO)
CSPI_SS is pulled up by the MMOD or the firmware
0.6V * (1 + (210/47)) = 3.28V
SPI1 CSn
C1=15pF, C2=15pF, CL=12pF, Cstray=5, (C1*C2)/(C1+C2)+Cstray == CL
SPI1 RX
SPI1 SCK
UART0 TX
0.6V * (1 + (200/200)) = 1.2V
RP can act as SPI slave on the CSPI bus.
SPI0 TX
USB1: FPGA USB DEVICE & POWER
"Differential Data Multiple Interface"
SPIO SCK
USB2: RP2040 USB DEVICE/DEBUG
The firmware uses PIO SPI to program the MMOD because this requires swapping SI/SO.
SPI0 RX
B O N B O N

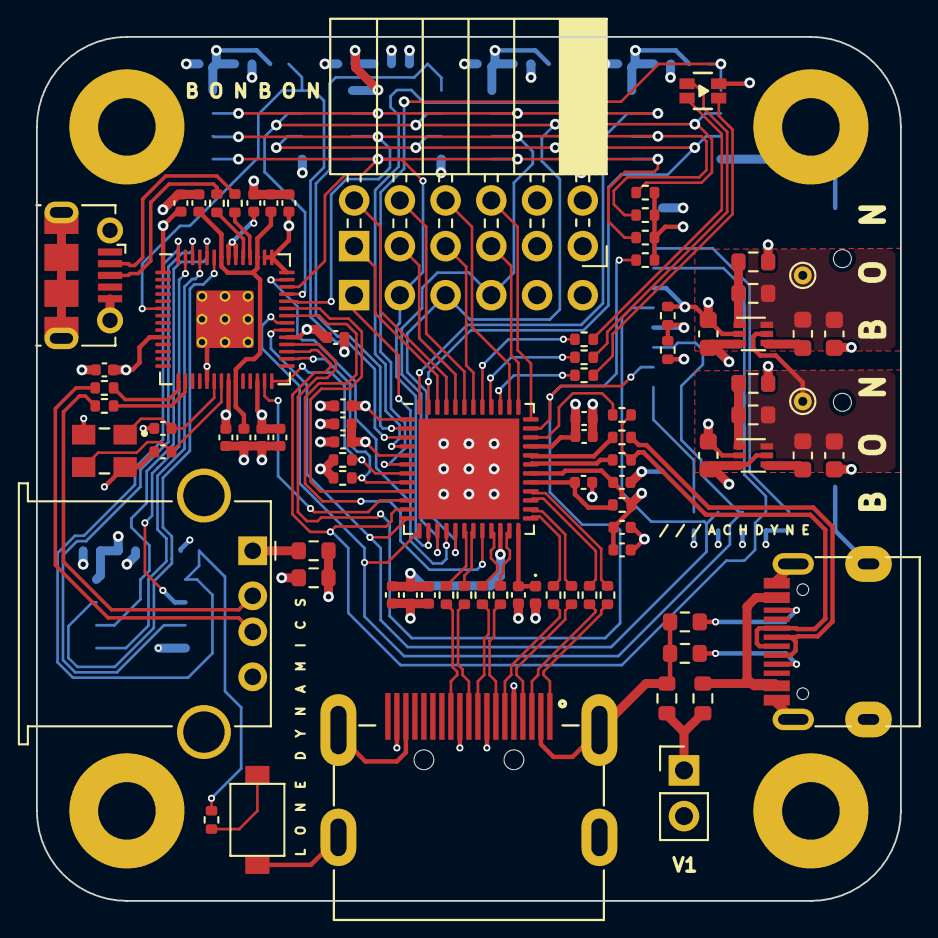
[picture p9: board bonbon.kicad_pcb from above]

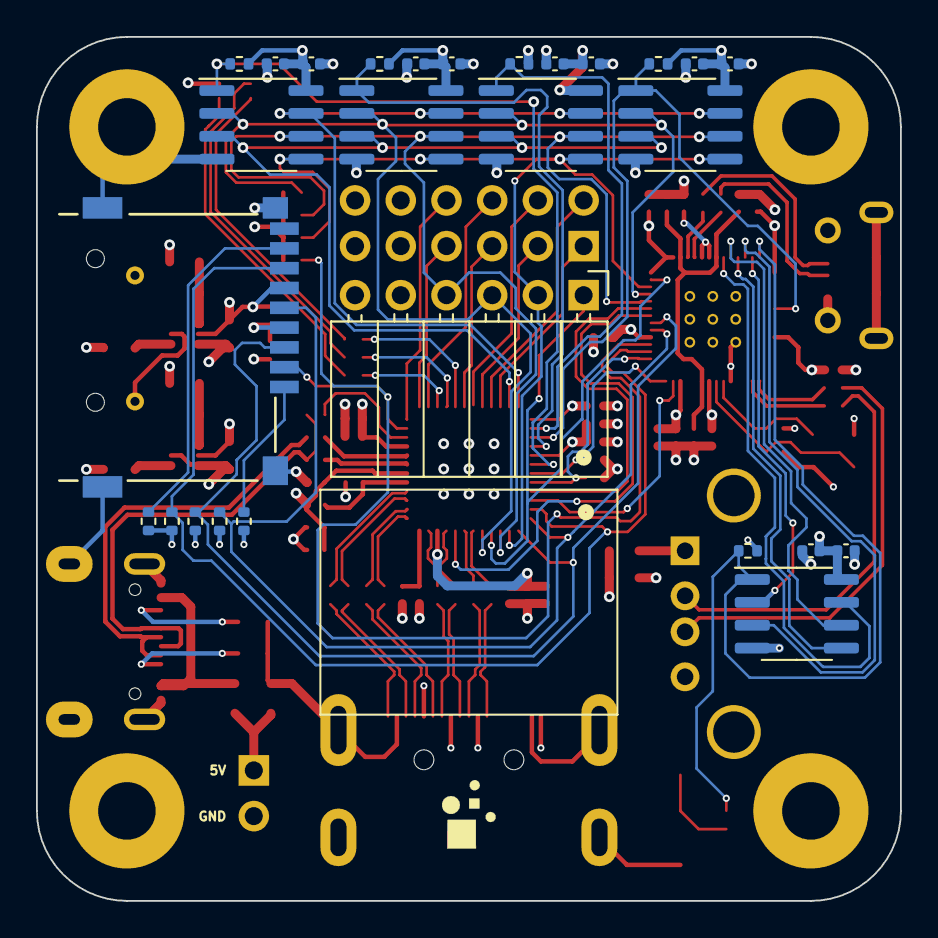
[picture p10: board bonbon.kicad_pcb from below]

Board: 4 copper layers, 48.0 x 48.0 mm, 117 parts (27 on the bottom side), 88 nets.

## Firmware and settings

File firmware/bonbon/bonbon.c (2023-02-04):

/**
 * Copyright (c) 2020 Raspberry Pi (Trading) Ltd.
 * Copyright (c) 2022 Lone Dynamics Corporation <info@lonedynamics.com>
 *
 * SPDX-License-Identifier: BSD-3-Clause
 *
 * Bonbon Firmware
 *
 */

#define MUSLI_SPI_RX_PIN	28
#define MUSLI_SPI_CSN_PIN	29
#define MUSLI_SPI_SCK_PIN	26
#define MUSLI_SPI_TX_PIN	27

#define MUSLI_CMD_READY 0x00
#define MUSLI_CMD_INIT 0x01

#define MUSLI_CMD_GPIO_SET_DIR 0x10
#define MUSLI_CMD_GPIO_DISABLE_PULLS 0x11
#define MUSLI_CMD_GPIO_PULL_UP 0x12
#define MUSLI_CMD_GPIO_PULL_DOWN 0x13

#define MUSLI_CMD_GPIO_GET 0x20
#define MUSLI_CMD_GPIO_PUT 0x21

#define MUSLI_CMD_SPI_READ 0x80
#define MUSLI_CMD_SPI_WRITE 0x81
#define MUSLI_CMD_CFG_PIO_SPI 0x8f

#define MUSLI_CMD_REBOOT 0xf0

#define ICE40_CDONE 17
#define ICE40_CRESET 19

#define RAM_SS0 4
#define SD_SS 15

#define SPI_MODE_HW 1
#define SPI_MODE_PIO 2

#include <stdio.h>
#include <strings.h>

// Pico
#include "pico/stdlib.h"
#include "hardware/spi.h"
#include "hardware/watchdog.h"
#include "pico/stdlib.h"
#include "pico/binary_info.h"
#include "pio_spi.h"

#include "hardware/pll.h"
#include "hardware/clocks.h"
#include "hardware/structs/pll.h"
#include "hardware/structs/clocks.h"

uint8_t spi_mode = SPI_MODE_HW;

void init_ldprog(void);
void init_gpio(void);
void init_pio_spi(void);
void init_bonbon(void);
void init_bonbon_postconf(void);
void pio_spi_cfg(uint8_t pin_sck, uint8_t pin_mosi, uint8_t pin_miso);

uint8_t spi_pio_offset;

bool bonbon_fpga_configured = false;

pio_spi_inst_t spi_pio = {
	.pio = pio0,
	.sm = 0
};

// For memcpy
#include <string.h>

// Include descriptor struct definitions
#include "usb_common.h"
// USB register definitions from pico-sdk
#include "hardware/regs/usb.h"
// USB hardware struct definitions from pico-sdk
#include "hardware/structs/usb.h"
// For interrupt enable and numbers
#include "hardware/irq.h"
// For resetting the USB controller
#include "hardware/resets.h"

// Device descriptors
#include "bonbon.h"

#define usb_hw_set hw_set_alias(usb_hw)
#define usb_hw_clear hw_clear_alias(usb_hw)

// Function prototypes for our device specific endpoint handlers defined
// later on
void ep0_in_handler(uint8_t *buf, uint16_t len);
void ep0_out_handler(uint8_t *buf, uint16_t len);
void ep1_out_handler(uint8_t *buf, uint16_t len);
void ep2_in_handler(uint8_t *buf, uint16_t len);

// Global device address
static bool should_set_address = false;
static uint8_t dev_addr = 0;
static volatile bool usb_configured = false;

// Global data buffer for EP0
static uint8_t ep0_buf[64];

// Struct defining the device configuration
static struct usb_device_configuration dev_config = {
        .device_descriptor = &device_descriptor,
        .interface_descriptor = &interface_descriptor,
        .config_descriptor = &config_descriptor,
        .lang_descriptor = lang_descriptor,
        .descriptor_strings = descriptor_strings,
        .endpoints = {
                {
                        .descriptor = &ep0_out,
                        .handler = &ep0_out_handler,
                        .endpoint_control = NULL, // NA for EP0
                        .buffer_control = &usb_dpram->ep_buf_ctrl[0].out,
                        // EP0 in and out share a data buffer
                        .data_buffer = &usb_dpram->ep0_buf_a[0],
                },
                {
                        .descriptor = &ep0_in,
                        .handler = &ep0_in_handler,
                        .endpoint_control = NULL, // NA for EP0,
                        .buffer_control = &usb_dpram->ep_buf_ctrl[0].in,
                        // EP0 in and out share a data buffer
                        .data_buffer = &usb_dpram->ep0_buf_a[0],
                },
                {
                        .descriptor = &ep1_out,
                        .handler = &ep1_out_handler,
                        // EP1 starts at offset 0 for endpoint control
                        .endpoint_control = &usb_dpram->ep_ctrl[0].out,
                        .buffer_control = &usb_dpram->ep_buf_ctrl[1].out,
                        // First free EPX buffer
                        .data_buffer = &usb_dpram->epx_data[0 * 64],
                },
                {
                        .descriptor = &ep2_in,
                        .handler = &ep2_in_handler,
                        .endpoint_control = &usb_dpram->ep_ctrl[1].in,
                        .buffer_control = &usb_dpram->ep_buf_ctrl[2].in,
                        // Second free EPX buffer
                        .data_buffer = &usb_dpram->epx_data[1 * 64],
                }
        }
};

/**
 * @brief Given an endpoint address, return the usb_endpoint_configuration of that endpoint. Returns NULL
 * if an endpoint of that address is not found.
 *
 * @param addr
 * @return struct usb_endpoint_configuration*
 */
struct usb_endpoint_configuration *usb_get_endpoint_configuration(uint8_t addr) {
    struct usb_endpoint_configuration *endpoints = dev_config.endpoints;
    for (int i = 0; i < USB_NUM_ENDPOINTS; i++) {
        if (endpoints[i].descriptor && (endpoints[i].descriptor->bEndpointAddress == addr)) {
            return &endpoints[i];
        }
    }
    return NULL;
}

/**
 * @brief Given a C string, fill the EP0 data buf with a USB string descriptor for that string.
 *
 * @param C string you would like to send to the USB host
 * @return the length of the string descriptor in EP0 buf
 */
uint8_t usb_prepare_string_descriptor(const unsigned char *str) {
    // 2 for bLength + bDescriptorType + strlen * 2 because string is unicode. i.e. other byte will be 0
    uint8_t bLength = 2 + (strlen((const char *)str) * 2);
    static const uint8_t bDescriptorType = 0x03;

    volatile uint8_t *buf = &ep0_buf[0];
    *buf++ = bLength;
    *buf++ = bDescriptorType;

    uint8_t c;

    do {
        c = *str++;
        *buf++ = c;
        *buf++ = 0;
    } while (c != '\0');

    return bLength;
}

/**
 * @brief Take a buffer pointer located in the USB RAM and return as an offset of the RAM.
 *
 * @param buf
 * @return uint32_t
 */
static inline uint32_t usb_buffer_offset(volatile uint8_t *buf) {
    return (uint32_t) buf ^ (uint32_t) usb_dpram;
}

/**
 * @brief Set up the endpoint control register for an endpoint (if applicable. Not valid for EP0).
 *
 * @param ep
 */
void usb_setup_endpoint(const struct usb_endpoint_configuration *ep) {
    printf("Set up endpoint 0x%x with buffer address 0x%p\n", ep->descriptor->bEndpointAddress, ep->data_buffer);

    // EP0 doesn't have one so return if that is the case
    if (!ep->endpoint_control) {
        return;
    }

    // Get the data buffer as an offset of the USB controller's DPRAM
    uint32_t dpram_offset = usb_buffer_offset(ep->data_buffer);
    uint32_t reg = EP_CTRL_ENABLE_BITS
                   | EP_CTRL_INTERRUPT_PER_BUFFER
                   | (ep->descriptor->bmAttributes << EP_CTRL_BUFFER_TYPE_LSB)
                   | dpram_offset;
    *ep->endpoint_control = reg;
}

/**
 * @brief Set up the endpoint control register for each endpoint.
 *
 */
void usb_setup_endpoints() {
    const struct usb_endpoint_configuration *endpoints = dev_config.endpoints;
    for (int i = 0; i < USB_NUM_ENDPOINTS; i++) {
        if (endpoints[i].descriptor && endpoints[i].handler) {
            usb_setup_endpoint(&endpoints[i]);
        }
    }
}

/**
 * @brief Set up the USB controller in device mode, clearing any previous state.
 *
 */
void usb_device_init() {
    // Reset usb controller
    reset_block(RESETS_RESET_USBCTRL_BITS);
    unreset_block_wait(RESETS_RESET_USBCTRL_BITS);

    // Clear any previous state in dpram just in case
    memset(usb_dpram, 0, sizeof(*usb_dpram)); // <1>

    // Enable USB interrupt at processor
    irq_set_enabled(USBCTRL_IRQ, true);

    // Mux the controller to the onboard usb phy
    usb_hw->muxing = USB_USB_MUXING_TO_PHY_BITS | USB_USB_MUXING_SOFTCON_BITS;

    // Force VBUS detect so the device thinks it is plugged into a host
    usb_hw->pwr = USB_USB_PWR_VBUS_DETECT_BITS | USB_USB_PWR_VBUS_DETECT_OVERRIDE_EN_BITS;

    // Enable the USB controller in device mode.
    usb_hw->main_ctrl = USB_MAIN_CTRL_CONTROLLER_EN_BITS;

    // Enable an interrupt per EP0 transaction
    usb_hw->sie_ctrl = USB_SIE_CTRL_EP0_INT_1BUF_BITS; // <2>

    // Enable interrupts for when a buffer is done, when the bus is reset,
    // and when a setup packet is received
    usb_hw->inte = USB_INTS_BUFF_STATUS_BITS |
                   USB_INTS_BUS_RESET_BITS |
                   USB_INTS_SETUP_REQ_BITS;

    // Set up endpoints (endpoint control registers)
    // described by device configuration
    usb_setup_endpoints();

    // Present full speed device by enabling pull up on DP
    usb_hw_set->sie_ctrl = USB_SIE_CTRL_PULLUP_EN_BITS;
}

/**
 * @brief Given an endpoint configuration, returns true if the endpoint
 * is transmitting data to the host (i.e. is an IN endpoint)
 *
 * @param ep, the endpoint configuration
 * @return true
 * @return false
 */
static inline bool ep_is_tx(struct usb_endpoint_configuration *ep) {
    return ep->descriptor->bEndpointAddress & USB_DIR_IN;
}

/**
 * @brief Starts a transfer on a given endpoint.
 *
 * @param ep, the endpoint configuration.
 * @param buf, the data buffer to send. Only applicable if the endpoint is TX
 * @param len, the length of the data in buf (this example limits max len to one packet - 64 bytes)
 */
void usb_start_transfer(struct usb_endpoint_configuration *ep, uint8_t *buf, uint16_t len) {
    // We are asserting that the length is <= 64 bytes for simplicity of the example.
    // For multi packet transfers see the tinyusb port.
    assert(len <= 64);

//    printf("Start transfer of len %d on ep addr 0x%x\n", len, ep->descriptor->bEndpointAddress);

    // Prepare buffer control register value
    uint32_t val = len | USB_BUF_CTRL_AVAIL;

    if (ep_is_tx(ep)) {
        // Need to copy the data from the user buffer to the usb memory
        memcpy((void *) ep->data_buffer, (void *) buf, len);
        // Mark as full
        val |= USB_BUF_CTRL_FULL;
    }

    // Set pid and flip for next transfer
    val |= ep->next_pid ? USB_BUF_CTRL_DATA1_PID : USB_BUF_CTRL_DATA0_PID;
    ep->next_pid ^= 1u;

    *ep->buffer_control = val;
}

/**
 * @brief Send device descriptor to host
 *
 */
void usb_handle_device_descriptor(void) {
    const struct usb_device_descriptor *d = dev_config.device_descriptor;
    // EP0 in
    struct usb_endpoint_configuration *ep = usb_get_endpoint_configuration(EP0_IN_ADDR);
    // Always respond with pid 1
    ep->next_pid = 1;
    usb_start_transfer(ep, (uint8_t *) d, sizeof(struct usb_device_descriptor));
}

/**
 * @brief Send the configuration descriptor (and potentially the configuration and endpoint descriptors) to the host.
 *
 * @param pkt, the setup packet received from the host.
 */
void usb_handle_config_descriptor(volatile struct usb_setup_packet *pkt) {
    uint8_t *buf = &ep0_buf[0];

    // First request will want just the config descriptor
    const struct usb_configuration_descriptor *d = dev_config.config_descriptor;
    memcpy((void *) buf, d, sizeof(struct usb_configuration_descriptor));
    buf += sizeof(struct usb_configuration_descriptor);

    // If we more than just the config descriptor copy it all
    if (pkt->wLength >= d->wTotalLength) {
        memcpy((void *) buf, dev_config.interface_descriptor, sizeof(struct usb_interface_descriptor));
        buf += sizeof(struct usb_interface_descriptor);
        const struct usb_endpoint_configuration *ep = dev_config.endpoints;

        // Copy all the endpoint descriptors starting from EP1
        for (uint i = 2; i < USB_NUM_ENDPOINTS; i++) {
            if (ep[i].descriptor) {
                memcpy((void *) buf, ep[i].descriptor, sizeof(struct usb_endpoint_descriptor));
                buf += sizeof(struct usb_endpoint_descriptor);
            }
        }

    }

    // Send data
    // Get len by working out end of buffer subtract start of buffer
    uint32_t len = (uint32_t) buf - (uint32_t) &ep0_buf[0];
    usb_start_transfer(usb_get_endpoint_configuration(EP0_IN_ADDR), &ep0_buf[0], len);
}

/**
 * @brief Handle a BUS RESET from the host by setting the device address back to 0.
 *
 */
void usb_bus_reset(void) {
    // Set address back to 0
    dev_addr = 0;
    should_set_address = false;
    usb_hw->dev_addr_ctrl = 0;
    usb_configured = false;
}

/**
 * @brief Send the requested string descriptor to the host.
 *
 * @param pkt, the setup packet from the host.
 */
void usb_handle_string_descriptor(volatile struct usb_setup_packet *pkt) {
    uint8_t i = pkt->wValue & 0xff;
    uint8_t len = 0;

    if (i == 0) {
        len = 4;
        memcpy(&ep0_buf[0], dev_config.lang_descriptor, len);
    } else {
        // Prepare fills in ep0_buf
        len = usb_prepare_string_descriptor(dev_config.descriptor_strings[i - 1]);
    }

    usb_start_transfer(usb_get_endpoint_configuration(EP0_IN_ADDR), &ep0_buf[0], len);
}

/**
 * @brief Sends a zero length status packet back to the host.
 */
void usb_acknowledge_out_request(void) {
    usb_start_transfer(usb_get_endpoint_configuration(EP0_IN_ADDR), NULL, 0);
}

/**
 * @brief Handles a SET_ADDR request from the host. The actual setting of the device address in
 * hardware is done in ep0_in_handler. This is because we have to acknowledge the request first
 * as a device with address zero.
 *
 * @param pkt, the setup packet from the host.
 */
void usb_set_device_address(volatile struct usb_setup_packet *pkt) {
    // Set address is a bit of a strange case because we have to send a 0 length status packet first with
    // address 0
    dev_addr = (pkt->wValue & 0xff);
    printf("Set address %d\r\n", dev_addr);
    // Will set address in the callback phase
    should_set_address = true;
    usb_acknowledge_out_request();
}

/**
 * @brief Handles a SET_CONFIGRUATION request from the host. Assumes one configuration so simply
 * sends a zero length status packet back to the host.
 *
 * @param pkt, the setup packet from the host.
 */
void usb_set_device_configuration(volatile struct usb_setup_packet *pkt) {
    // Only one configuration so just acknowledge the request
    printf("Device Enumerated\r\n");
    usb_acknowledge_out_request();
    usb_configured = true;
}

/**
 * @brief Respond to a setup packet from the host.
 *
 */
void usb_handle_setup_packet(void) {
    volatile struct usb_setup_packet *pkt = (volatile struct usb_setup_packet *) &usb_dpram->setup_packet;
    uint8_t req_direction = pkt->bmRequestType;
    uint8_t req = pkt->bRequest;

    // Reset PID to 1 for EP0 IN
    usb_get_endpoint_configuration(EP0_IN_ADDR)->next_pid = 1u;

    if (req_direction == USB_DIR_OUT) {
        if (req == USB_REQUEST_SET_ADDRESS) {
            usb_set_device_address(pkt);
        } else if (req == USB_REQUEST_SET_CONFIGURATION) {
            usb_set_device_configuration(pkt);
        } else {
            usb_acknowledge_out_request();
            printf("Other OUT request (0x%x)\r\n", pkt->bRequest);
        }
    } else if (req_direction == USB_DIR_IN) {
        if (req == USB_REQUEST_GET_DESCRIPTOR) {
            uint16_t descriptor_type = pkt->wValue >> 8;

            switch (descriptor_type) {
                case USB_DT_DEVICE:
                    usb_handle_device_descriptor();
                    printf("GET DEVICE DESCRIPTOR\r\n");
                    break;

                case USB_DT_CONFIG:
                    usb_handle_config_descriptor(pkt);
                    printf("GET CONFIG DESCRIPTOR\r\n");
                    break;

                case USB_DT_STRING:
                    usb_handle_string_descriptor(pkt);
                    printf("GET STRING DESCRIPTOR\r\n");
                    break;

                default:
                    printf("Unhandled GET_DESCRIPTOR type 0x%x\r\n", descriptor_type);
            }
        } else {
            printf("Other IN request (0x%x)\r\n", pkt->bRequest);
        }
    }
}

/**
 * @brief Notify an endpoint that a transfer has completed.
 *
 * @param ep, the endpoint to notify.
 */
static void usb_handle_ep_buff_done(struct usb_endpoint_configuration *ep) {
    uint32_t buffer_control = *ep->buffer_control;
    // Get the transfer length for this endpoint
    uint16_t len = buffer_control & USB_BUF_CTRL_LEN_MASK;

    // Call that endpoints buffer done handler
    ep->handler((uint8_t *) ep->data_buffer, len);
}

/**
 * @brief Find the endpoint configuration for a specified endpoint number and
 * direction and notify it that a transfer has completed.
 *
 * @param ep_num
 * @param in
 */
static void usb_handle_buff_done(uint ep_num, bool in) {
    uint8_t ep_addr = ep_num | (in ? USB_DIR_IN : 0);
//    printf("EP %d (in = %d) done\n", ep_num, in);
    for (uint i = 0; i < USB_NUM_ENDPOINTS; i++) {
        struct usb_endpoint_configuration *ep = &dev_config.endpoints[i];
        if (ep->descriptor && ep->handler) {
            if (ep->descriptor->bEndpointAddress == ep_addr) {
                usb_handle_ep_buff_done(ep);
                return;
            }
        }
    }
}

/**
 * @brief Handle a "buffer status" irq. This means that one or more
 * buffers have been sent / received. Notify each endpoint where this
 * is the case.
 */
static void usb_handle_buff_status() {
    uint32_t buffers = usb_hw->buf_status;
    uint32_t remaining_buffers = buffers;

    uint bit = 1u;
    for (uint i = 0; remaining_buffers && i < USB_NUM_ENDPOINTS * 2; i++) {
        if (remaining_buffers & bit) {
            // clear this in advance
            usb_hw_clear->buf_status = bit;
            // IN transfer for even i, OUT transfer for odd i
            usb_handle_buff_done(i >> 1u, !(i & 1u));
            remaining_buffers &= ~bit;
        }
        bit <<= 1u;
    }
}

/**
 * @brief USB interrupt handler
 *
 */
/// \tag::isr_setup_packet[]
void isr_usbctrl(void) {
    // USB interrupt handler
    uint32_t status = usb_hw->ints;
    uint32_t handled = 0;

    // Setup packet received
    if (status & USB_INTS_SETUP_REQ_BITS) {
        handled |= USB_INTS_SETUP_REQ_BITS;
        usb_hw_clear->sie_status = USB_SIE_STATUS_SETUP_REC_BITS;
        usb_handle_setup_packet();
    }
/// \end::isr_setup_packet[]

    // Buffer status, one or more buffers have completed
    if (status & USB_INTS_BUFF_STATUS_BITS) {
        handled |= USB_INTS_BUFF_STATUS_BITS;
        usb_handle_buff_status();
    }

    // Bus is reset
    if (status & USB_INTS_BUS_RESET_BITS) {
        printf("BUS RESET\n");
        handled |= USB_INTS_BUS_RESET_BITS;
        usb_hw_clear->sie_status = USB_SIE_STATUS_BUS_RESET_BITS;
        usb_bus_reset();
    }

    if (status ^ handled) {
        panic("Unhandled IRQ 0x%x\n", (uint) (status ^ handled));
    }
}

/**
 * @brief EP0 in transfer complete. Either finish the SET_ADDRESS process, or receive a zero
 * length status packet from the host.
 *
 * @param buf the data that was sent
 * @param len the length that was sent
 */
void ep0_in_handler(uint8_t *buf, uint16_t len) {
    if (should_set_address) {
        // Set actual device address in hardware
        usb_hw->dev_addr_ctrl = dev_addr;
        should_set_address = false;
    } else {
        // Receive a zero length status packet from the host on EP0 OUT
        struct usb_endpoint_configuration *ep = usb_get_endpoint_configuration(EP0_OUT_ADDR);
        usb_start_transfer(ep, NULL, 0);
    }
}

void ep0_out_handler(uint8_t *buf, uint16_t len) {
}
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
int main(void) {

	// set the sys clock to 126mhz
	set_sys_clock_khz(126000, true);

	stdio_init_all();
	printf("Bonbon initializing ...\n");

/*
	printf("clocks: ");
    uint f_pll_sys = frequency_count_khz(CLOCKS_FC0_SRC_VALUE_PLL_SYS_CLKSRC_PRIMARY);
    uint f_pll_usb = frequency_count_khz(CLOCKS_FC0_SRC_VALUE_PLL_USB_CLKSRC_PRIMARY);
    uint f_rosc = frequency_count_khz(CLOCKS_FC0_SRC_VALUE_ROSC_CLKSRC);
    uint f_clk_sys = frequency_count_khz(CLOCKS_FC0_SRC_VALUE_CLK_SYS);
    uint f_clk_peri = frequency_count_khz(CLOCKS_FC0_SRC_VALUE_CLK_PERI);
    uint f_clk_usb = frequency_count_khz(CLOCKS_FC0_SRC_VALUE_CLK_USB);
    uint f_clk_adc = frequency_count_khz(CLOCKS_FC0_SRC_VALUE_CLK_ADC);
    uint f_clk_rtc = frequency_count_khz(CLOCKS_FC0_SRC_VALUE_CLK_RTC);
 
    printf("pll_sys  = %dkHz\n", f_pll_sys);
    printf("pll_usb  = %dkHz\n", f_pll_usb);
    printf("rosc     = %dkHz\n", f_rosc);
    printf("clk_sys  = %dkHz\n", f_clk_sys);
    printf("clk_peri = %dkHz\n", f_clk_peri);
    printf("clk_usb  = %dkHz\n", f_clk_usb);
    printf("clk_adc  = %dkHz\n", f_clk_adc);
    printf("clk_rtc  = %dkHz\n", f_clk_rtc);
*/

	printf("enable clock output ...\n");
//	clock_gpio_init(24, CLOCKS_CLK_GPOUT2_CTRL_AUXSRC_VALUE_CLK_SYS, 1);
	clock_gpio_init(24, CLOCKS_CLK_GPOUT2_CTRL_AUXSRC_VALUE_CLK_USB, 1);
//	clock_gpio_init(24, CLOCKS_CLK_GPOUT2_CTRL_AUXSRC_VALUE_CLKSRC_PLL_USB, 1);

	printf("usb_device_init ...\n");
	usb_device_init();

	printf("loading spi_pio ...\n");
	spi_pio_offset = pio_add_program(spi_pio.pio, &spi_cpha0_program);
	printf("loaded PIO program at %d\n", spi_pio_offset);

	init_bonbon();
	ice40_reset();

   int kfc_prev = 0;
   int usb_started = 0;

	// Everything is interrupt driven so just loop here
	while (1) {

		tight_loop_contents();

		if (usb_configured && !usb_started) {
			usb_start_transfer(usb_get_endpoint_configuration(EP1_OUT_ADDR),
				NULL, 64);
			usb_started = 1;
		}

		int cdone = gpio_get(ICE40_CDONE);
		if (cdone && cdone != kfc_prev && !bonbon_fpga_configured) {
			init_bonbon_postconf();
		}
		kfc_prev = cdone;

	}

	return 0;

}

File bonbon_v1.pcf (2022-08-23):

# Bonbon V1
# ---------

# CLOCK
set_io CLK_RP	20		# RP_GPIO24

# RGB LED
set_io LED_R	40
set_io LED_G	41
set_io LED_B	39

# PMOD_A
set_io PMOD_A1		46
set_io PMOD_A2		44
set_io PMOD_A3		42
set_io PMOD_A4		37
set_io PMOD_A7		45
set_io PMOD_A8		43
set_io PMOD_A9		38
set_io PMOD_A10	36

# UART ON PMOD_A
set_io UART0_RTS  46
set_io UART0_RX   44
set_io UART0_TX   42
set_io UART0_CTS  37

# USB
set_io USB_DP		31
set_io USB_DP_PU	34
set_io USB_DN		32

# DDMI
set_io DDMI_D0_N	21
set_io DDMI_D1_N	25
set_io DDMI_D2_N	27
set_io DDMI_CK_N	18
set_io DDMI_D0_P	23
set_io DDMI_D1_P	26
set_io DDMI_D2_P	28
set_io DDMI_CK_P	19

# MICROSD
set_io SD_SS		35		# RP_GPIO21
set_io SD_MISO		11		# RP_GPIO20
set_io SD_MOSI		13		# RP_GPIO23
set_io SD_SCK		12		# RP_GPIO22

# RP2040 GPIO
set_io RP_TX		10		# RP_GPIO16
set_io RP_RX		7		# CDONE / RP_GPIO17

# SPI BUS
set_io SPI_SS_RAM0	3	# RP_GPIO4
set_io SPI_SS_RAM1	2
set_io SPI_SS_RAM2	4
set_io SPI_SS_RAM3	6
set_io SPI_SS_RP		9	# RP_GPIO25
set_io SPI_SS_FLASH	16 # CSPI_SS
set_io SPI_SCK			15 # CSPI_SCK / RP_GPIO26
set_io SPI_MISO		17	# CSPI_SI / RP_GPIO27
set_io SPI_MOSI		14	# CSPI_SO / RP_GPIO28
set_io SPI_IO2			47
set_io SPI_IO3			48

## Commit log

2022-08-23 add schematics
2023-02-01 fix wrong gpio for cdone
    [bonbon.c]
2023-05-22 add pcb
    [bonbon.kicad_pcb, bonbon.kicad_sch]

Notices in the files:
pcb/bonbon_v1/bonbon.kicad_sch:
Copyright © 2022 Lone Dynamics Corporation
